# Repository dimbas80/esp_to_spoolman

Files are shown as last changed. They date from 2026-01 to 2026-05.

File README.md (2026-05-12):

# ESP_TO_SPOOLMAN
Данный проект реализует считывание NFC меток типа NTAG2xx установленных на катушках с филаментом, и установку активной катушки в сервис [Spoolman]([https://github.com/ManuelW77/Filaman](https://github.com/Donkie/Spoolman#integration-status))  через Moonraker. Spoolman должен быть установлен и настроен в вашей сети и принтере.
## Используемые компоненты
1. Контроллер ESP32-C3 super mini
2. Считыватель NFC меток RFID-RC522
3. Светодиод WS2812B
4. Кнопка
5. Метки NTAG215, NTAG216
   
Проект выполнен для ESP32-C3 но можно установить на другой тип ESP32  с заменой пинов на соотвествующие.
Имеется web-интерфейс для настройки wifi и адресов серверов Spoolman и Moonraker. Так же там отображается состояние доступности серверов, считывателя и данные полученные с метки.

## Запись меток
Запись меток осуществляется с помощью проекта [FilaMan](https://github.com/ManuelW77/Filaman)
Метки можно применять такие NTAG215 
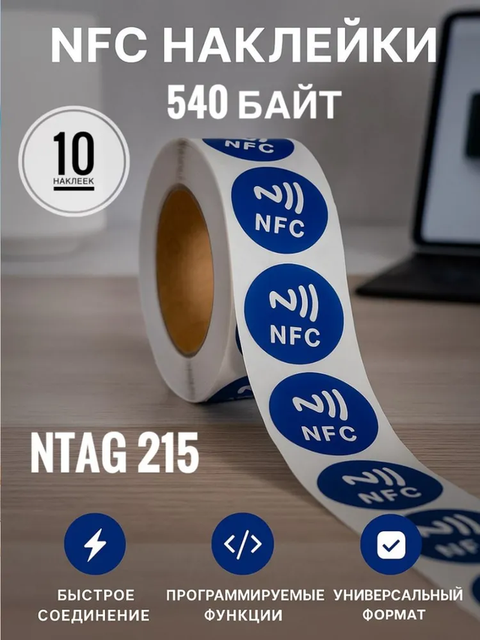
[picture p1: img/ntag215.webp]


## СХЕМА
Схема подключения модуля и ESP32

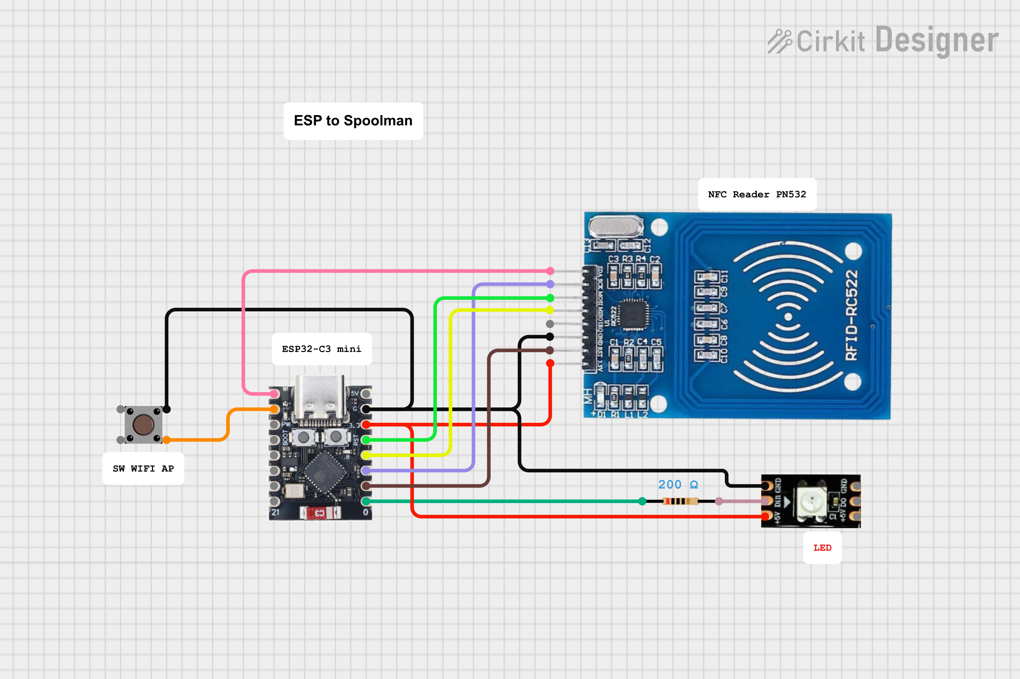
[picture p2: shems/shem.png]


## Pinout ESP32-C3 super mini
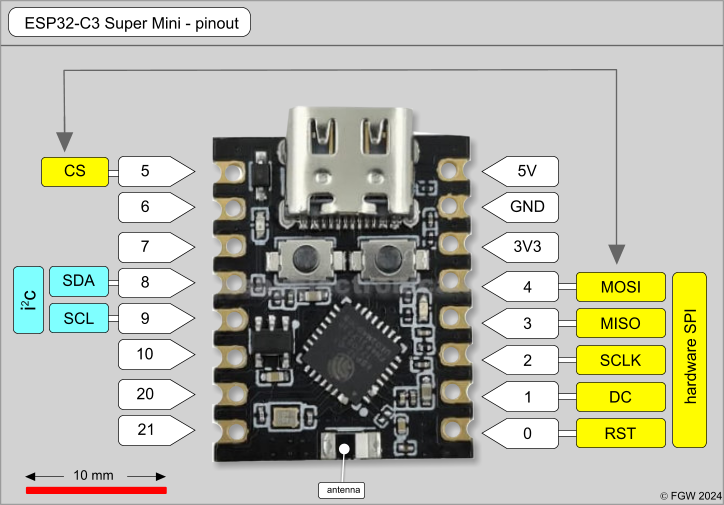
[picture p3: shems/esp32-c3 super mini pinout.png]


## Работа устройства
При включении ESP создает точку доступа с именем "ESP to Spoolman" и будет мигать синий светодиод к которой необходимо подключиться и перейти по IP 192.168.4.1. В  настройках необходимо ввести данные свой wifi сети, IP адрес сервера Spoolman, и IP адрес сервера Moonraker (ваш принтер с Klipper). И нажать кнопку "Save&Restart". После переподключения должны гореть зеленые светодиоды о доступности серверов и считывателя NFC. При необходимости нажать кнопку "Проверка статуса серверов". Светодиод на устройстве должен гороть зеленым. При поднисении метки к считывателю и успешном считывании метки светодиод мигнет желтым и установиться текущая катушка в web-интерфейсе вашего принтера. В случае ошибки чтения метки светодиод мигнет красным. Если красный горит постоянно значить потеряна связь с сервером или сетью. Подробный вывод ошибок и текущего состояния можно увидеть в логе в web-интерфейсе.

При включении переключателя "Устанавливать в MMU" будет также отправляться на принтер команда MMU_GATE_MAP NEXT_SPOOLID="spool_id". При этом если вы за время указанное в настройках вашего Happy Hare вставите в затвор пруток, то он установиться к карту затворов. Интеграция Happy Hare и Spoolman должна быть включена

## Вид web-интерфейса устройства
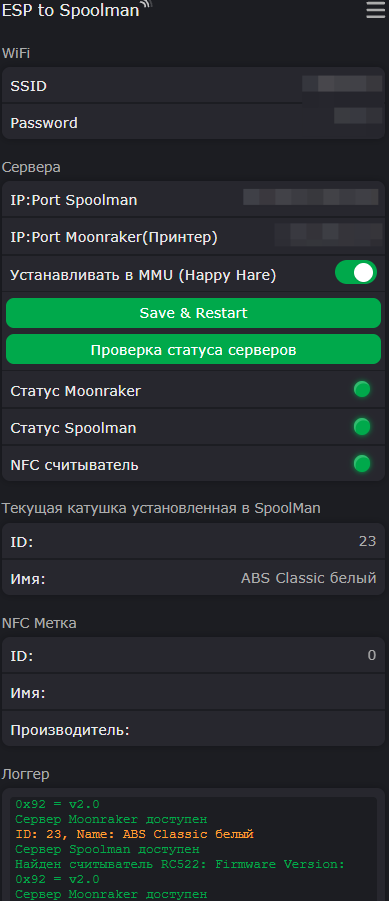
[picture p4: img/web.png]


## Вид web-интерфейса принтера с установленной катушкой
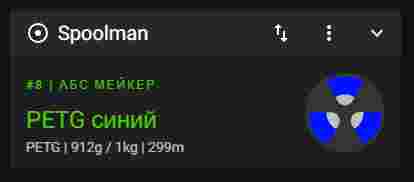
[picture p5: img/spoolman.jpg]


## Общий вид устройства
Файлы для печати доступны в папке cad

Общий вид устройства в корпусе 

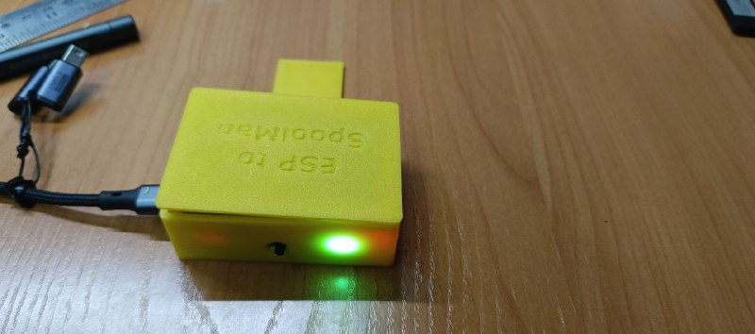
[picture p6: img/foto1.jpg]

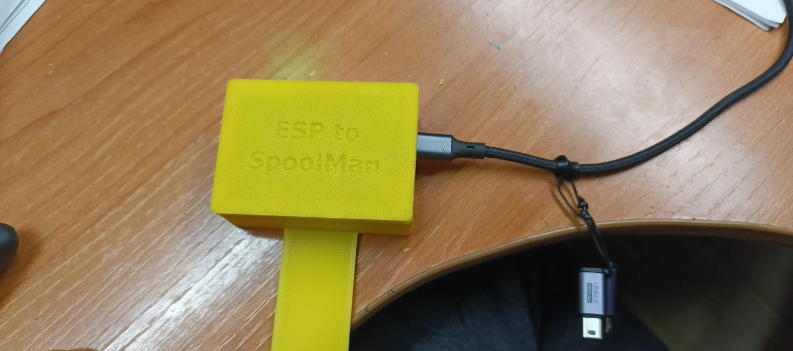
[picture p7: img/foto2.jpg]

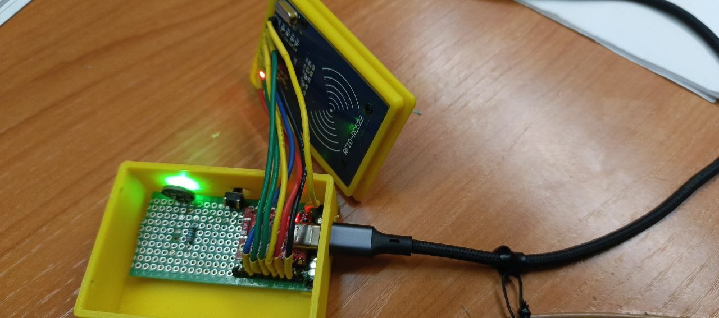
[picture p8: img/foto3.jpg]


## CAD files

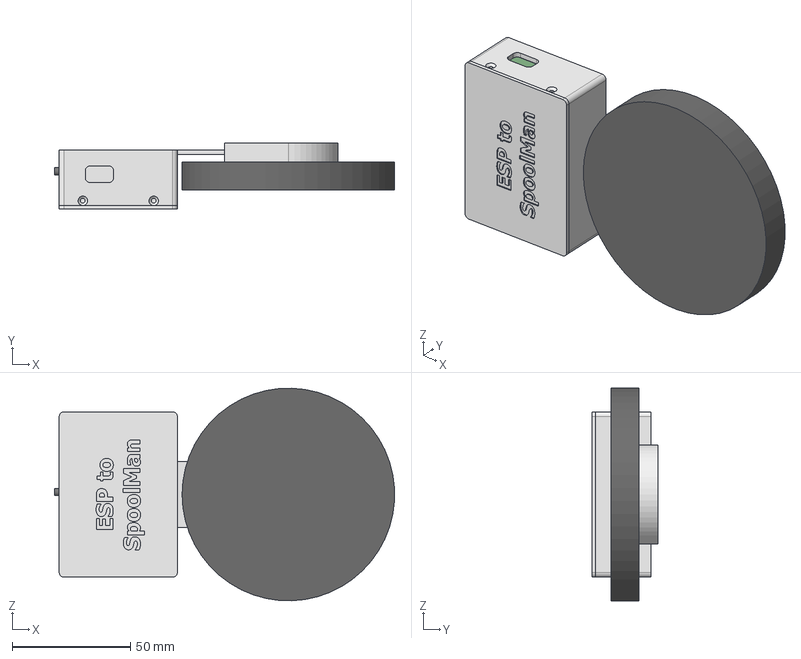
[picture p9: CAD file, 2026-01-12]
cad/ESP_to_Spoolman.stp
143.9 x 28.0 x 90.0 mm
Основа
RC522
Держатель катушки
КорпусNFC
Макетная плата 30х70
ESP32-C3_super_mini_scaled
Кнопка 6х6 на плату v2
Крышка

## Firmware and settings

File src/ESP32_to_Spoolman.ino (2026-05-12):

/*
Установка по NFC метке катушки в очередь печати Spoolman, Moonraker
автор: Dimbas80
*/
#define VER "1.0"
////////////////////////
//Библиотеки
///////////////////////

//ПИНЫ
#define SW_WIFI 6  //Пин Кнопки перевода в режим АР при загрузке

#include <WiFi.h>
#include <HTTPClient.h>
#include <StringUtils.h>
#include <Arduino.h>
#include <ArduinoJson.h>

//Светодиод WS2812
#include <FastLED.h>
#define NUMLEDS 1
#define PIN_DATA 0
#define BRIGHTNESS 100
#define LED_TYPE WS2812B
#define COLOR_ORDER GRB
#define RED 0
#define BLUE 150
#define GREEN 100
#define YELLOW 30
#define LIME 60

CRGB leds[NUMLEDS];

//============= NFC MFRC522 ===============
#include <MFRC522v2.h>
#include <MFRC522DriverSPI.h>
#include <MFRC522DriverPinSimple.h>
#include <MFRC522Debug.h>
#define RST_PIN 1  // Configurable, see typical pin layout above
#define SS_PIN 5   // Configurable, see typical pin layout above

MFRC522DriverPinSimple ss_pin(SS_PIN);  // Create pin driver. See typical pin layout above.
MFRC522DriverSPI driver{ ss_pin };      // Create SPI driver.
MFRC522 mfrc522{ driver };              // Create MFRC522 instance.

//=================== DB ==================
#include <GyverDBFile.h>
#include <LittleFS.h>
GyverDBFile db(&LittleFS, "/data.db");

#include <SettingsGyver.h>
SettingsGyver sett("ESP to Spoolman", &db);

sets::Logger logger(2000);  // размер буфера

WiFiServer server(80);

//имена ячеек базы данных
DB_KEYS(
  web,
  wifi_ssid,
  wifi_pass,
  serverSpoolman,
  serverMoonraker,
  apply1,
  apply2,
  led_sp,
  led_mn,
  led_nfc,
  sw_mmu,
  id,
  filament,
  nfc_id,
  nfc_name,
  nfc_brand,
  nfc_color,
  nfc_par);

//Переменные
bool LED_SP = false;        // WEB светодиод доступности спулман
bool LED_MN = false;        // WEB светодиод доступности Moonraker
bool LED_NFC = false;       // WEB светодиод доступности NFC считывателя
int curentID;               // ID текущей катушки
const char* filament_name;  // Имя филамента
bool wifiSettingMode = 0;   //Перемнная режима WIFI. 0 - SSID, 1 - AP
bool fl_status = false;     //флаг статуса
bool fl_led = false;        //флаг led
bool mmu = false;           //включение отправки данныех в MMU


//===========Таймеры=====================
#include <TimerMs.h>
TimerMs T_LED_WIFI(500, 1, 0);   //Периодичность мигания светодиода WIFI
TimerMs ResetLED(1000, 1, 0);    //Таймер сброса светодиода
TimerMs RebootNFC(60000, 1, 0);  //Таймер сброса NFC против зависания

//Интерфейс настроек
void build(sets::Builder& b) {
  {
    sets::Group g(b, "WiFi");
    b.Input(web::wifi_ssid, "SSID");
    b.Pass(web::wifi_pass, "Password");
  }
  {
    sets::Group g(b, "Сервера");
    if (b.Input(web::serverSpoolman, "IP:Port Spoolman")) {
      logger.println("Set IP:Port Spoolman:" + String(db[web::serverSpoolman]));
      db.update();
      //statusServer();
      //curent_filament_name(curentID);
    }
    if (b.Input(web::serverMoonraker, "IP:Port Moonraker(Принтер)")) {
      logger.println("Set IP:Port Moonraker(Принтер):" + String(db[web::serverMoonraker]));
      db.update();
      //statusServer();
    }
    //Переключатель MMU
    if (b.Switch(web::sw_mmu, "Устанавливать в MMU (Happy Hare)", &mmu)) {
      // Если по клику на переключатель мы хотим сохранить значение сразу:
      db[web::sw_mmu] = mmu;  // Синхронизируем значение с базой данных
      db.update();            // Записываем в ПЗУ
    }

    if (b.Button(web::apply1, "Save & Restart")) {
      db.update();  // сохраняем БД не дожидаясь таймаута
      ESP.restart();
    }
    if (b.Button(web::apply2, "Проверка статуса серверов")) {
      fl_status = true;
    }
    b.LED(web::led_mn, "Статус Moonraker", LED_MN, sets::Colors::Yellow, sets::Colors::Green);
    b.LED(web::led_sp, "Статус Spoolman", LED_SP, sets::Colors::Yellow, sets::Colors::Green);
    b.LED(web::led_nfc, "NFC считыватель", LED_NFC, sets::Colors::Yellow, sets::Colors::Green);
  }
  {
    sets::Group g(b, "Текущая катушка установленная в SpoolMan");
    b.Label(web::id, "ID:");
    b.Label(web::filament, "Имя:");
  }
  {
    sets::Group g(b, "NFC Метка");
    b.Label(web::nfc_id, "ID:");
    b.Label(web::nfc_name, "Имя:");
    b.Label(web::nfc_brand, "Производитель:");
    //b.Label(web::nfc_color, "Цвет:");
  }

  {
    sets::Group g(b, "Логгер");
    b.Log(H(log), logger);
  }
}


void update(sets::Updater& upd) {
  // отправить лог
  upd.update(H(log), logger);
}


/*==================================
            S E T U P 
====================================
*/
void setup() {
  Serial.begin(115200);
  T_LED_WIFI.setPeriodMode();
  RebootNFC.setPeriodMode();
  ResetLED.setPeriodMode();

  //============Светодиод=============
  FastLED.addLeds<LED_TYPE, PIN_DATA, COLOR_ORDER>(leds, NUMLEDS);
  FastLED.setBrightness(BRIGHTNESS);
  FastLED.clear();
  FastLED.show();

  //============= WIFI ===============

  WiFi.mode(WIFI_AP_STA);

  //============= Web интерфейс ===============

  sett.begin();
  sett.onBuild(build);
  sett.onUpdate(update);
  sett.config.updateTout = 1000;
  sett.setVersion(VER);


  //Инициализация базы данных настроек
  LittleFS.begin(true);
  db.begin();
  db.init(web::wifi_ssid, "");
  db.init(web::wifi_pass, "");
  db.init(web::serverMoonraker, "");
  db.init(web::serverSpoolman, "");
  db.init(web::nfc_id, 0);
  db.init(web::nfc_name, "");
  db.init(web::nfc_brand, "");
  db.init(web::nfc_color, "");
  db.init(web::id, 0);
  db.init(web::filament, "");
  mmu = db[web::sw_mmu]; 
  db[web::nfc_id] = 0;
  db[web::nfc_name] = "";
  db[web::nfc_brand] = "";
  db[web::nfc_color] = "";
  db[web::id] = 0;
  db[web::filament] = "";

  //Входы выходы
  pinMode(SW_WIFI, INPUT_PULLUP);  //Кнопка сброса WIFI


  //============ WIFI AP ========
  //Включаем точку доступа при нажатой кнопке или если не задан логин
  if (digitalRead(SW_WIFI) == 0 or !db[web::wifi_ssid].length()) {
    wifiSettingMode = 1;
    // ======= AP =======
    WiFi.softAP("AP ESP_to_Spoolman");
    Serial.print("AP IP: ");
    Serial.println(WiFi.softAPIP());
  }


  // ======= STA =======
  // если логин задан - подключаемся
  if (digitalRead(SW_WIFI) == 1 and db[web::wifi_ssid].length()) {
    wifiSettingMode = 0;
    WiFi.begin(db[web::wifi_ssid], db[web::wifi_pass]);
    Serial.print("Connect STA");
    int tries = 20;
    while (WiFi.status() != WL_CONNECTED) {
      delay(500);
      Serial.print('.');
      if (!--tries) break;
    }
    Serial.println();
    Serial.print(F("IP: "));
    Serial.println(WiFi.localIP());
    server.begin();
    WiFi.softAPdisconnect(true);
  }

  if (WiFi.status() == WL_CONNECTED) {
    statusServer();
    curent_filament_name(curentID);
  }

  //============= инициализация считывателя RC522 ===============

  pinMode(RST_PIN, OUTPUT);
  digitalWrite(RST_PIN, HIGH);

  mfrc522.PCD_Init();                                      // Init MFRC522
  mfrc522.PCD_SetAntennaGain(0x07);                        // Установка усиления антенны
  mfrc522.PCD_AntennaOff();                                // Перезагружаем антенну
  mfrc522.PCD_AntennaOn();                                 // Включаем антенну
  MFRC522Debug::PCD_DumpVersionToSerial(mfrc522, Serial);  // Show details of PCD - MFRC522 Card Reader details.
  delay(100);

  if (mfrc522.PCD_PerformSelfTest()) {
    Serial.print("Найден считыватель RC522: ");
    MFRC522Debug::PCD_DumpVersionToSerial(mfrc522, Serial);  // Show version of PCD - MFRC522 Card Reader.
    logger.print("Найден считыватель RC522: ");
    MFRC522Debug::PCD_DumpVersionToSerial(mfrc522, logger);  // Show version of PCD - MFRC522 Card Reader.
    LED_NFC = true;
  } else {
    Serial.println("Не найден считыватель RC522");
    logger.println(sets::Logger::error() + "Не найден считыватель RC522");
    LED_NFC = false;
  }
}

/*=================================
         L O O P
===================================         
*/
void loop() {
  sett.tick();
  T_LED_WIFI.tick();
  ResetLED.tick();
  RebootNFC.tick();


  //Переодический ребут считывателя и проверка статуса серверов
  if (RebootNFC.ready()) {
    resetMFRC();
    statusServer();
    curent_filament_name(curentID);
  }

  //Переодический сброс флага светодиода
  if (ResetLED.ready()) {
    fl_led = false;
  }

  //Читаем метку
  if (mfrc522.PCD_PerformSelfTest()) {
    readNFC();
  }

  //Мигаем светодиодом в режиме АР
  if (wifiSettingMode == 1) {
    if (T_LED_WIFI.ready()) {
      leds[0].setHue(BLUE);
      FastLED.show();
    } else {
      FastLED.clear();
      FastLED.show();
    }
  }
  //При подключении WIFI и доступности серверов включаем светодиод
  if (fl_led == false and wifiSettingMode == 0) {
    if (wifiSettingMode == 0 and WiFi.status() == WL_CONNECTED) {
      leds[0].setHue(BLUE);
      FastLED.show();
      if (LED_MN == 1 and LED_SP == 1 and LED_NFC == true) {
        leds[0].setHue(GREEN);
        FastLED.show();
      }
    } else {
      leds[0].setHue(RED);
      FastLED.show();
    }
  }

  //Читаем Serial если "status", то выводим статус серверов и текующую установленную катушку, если число, то устанавливаем катушку с числом если найдена
  if (Serial.available()) {
    String i = Serial.readString();
    String status = F("status");
    if (i == status) {
      statusServer();
      curent_filament_name(curentID);
    } else {
      int setID = i.toInt();
      SetSpool(setID);
    }
  } else if (fl_status == true) {
    fl_status = false;
    statusServer();
    curent_filament_name(curentID);
  }
}


/*===============================
============ ФУНКЦИИ ============
=================================
*/
//Светодиод WS2812
void set_led_color(int color) {
  leds[0].setHue(color);
  FastLED.show();
  fl_led = true;
}

// Ошибка ответа сервера
void errorServer(String error) {
  Serial.println("Ошибка ответа сервера: " + String(error));
  logger.println(sets::Logger::error() + "Ошибка ответа сервера: " + String(error));
  set_led_color(RED);
  return;
}

//Сброс считываетля
void resetMFRC() {
  digitalWrite(RST_PIN, LOW);        // Сбрасываем модуль
  delayMicroseconds(100);            // Ждем
  digitalWrite(RST_PIN, HIGH);       // Отпускаем сброс
  mfrc522.PCD_Init();                // Инициализируем заного
  mfrc522.PCD_SetAntennaGain(0x07);  // Установка усиления антенны
  mfrc522.PCD_AntennaOff();          // Перезагружаем антенну
  mfrc522.PCD_AntennaOn();           // Включаем антенну
  Serial.println(F("Reboot RC522"));
  MFRC522Debug::PCD_DumpVersionToSerial(mfrc522, Serial);
  if (mfrc522.PCD_PerformSelfTest()) {
    Serial.println("Найден считыватель RC522: ");
    MFRC522Debug::PCD_DumpVersionToSerial(mfrc522, Serial);  // Show version of PCD - MFRC522 Card Reader.
    logger.print("Найден считыватель RC522: ");
    MFRC522Debug::PCD_DumpVersionToSerial(mfrc522, logger);  // Show version of PCD - MFRC522 Card Reader.
    LED_NFC = true;
  } else {
    Serial.println("Не найден считыватель RC522");
    logger.println(sets::Logger::error() + "Не найден считыватель RC522");
    LED_NFC = false;
  }
}

//Статус сервера
void statusServer() {
  if (WiFi.status() == WL_CONNECTED) {
    HTTPClient http;
    String geturl = "http://" + String(db[web::serverMoonraker]) + "/server/spoolman/status";

    http.begin(geturl);

    http.setFollowRedirects(HTTPC_FORCE_FOLLOW_REDIRECTS);
    http.addHeader("Content-Type", "application/json");

    int httpResponseCode = http.GET();

    if (httpResponseCode > 0) {
      String response = http.getString();
      JsonDocument doc;
      DeserializationError error = deserializeJson(doc, response);
      http.end();
      //Проверка на ошибки ответа от сервера
      if (error) {
        String err = error.f_str();
        errorServer(err);
        http.end();
        LED_MN = false;
        return;
      }

      bool statusServer = doc["result"]["spoolman_connected"];
      curentID = doc["result"]["spool_id"];
      db[web::id] = curentID;

      if (statusServer) {
        Serial.println("Сервер Moonraker доступен");
        logger.println("Сервер Moonraker доступен");
        LED_MN = true;
        sett.reload();
      } else {
        Serial.println("Сервер Moonraker не доступен");
        logger.println(sets::Logger::error() + "Сервер Moonraker не доступен");
        LED_MN = false;
        sett.reload();
        return;
      }
    } else {
      errorServer(String(httpResponseCode));
      http.end();
      LED_MN = false;
      return;
    }
  }
}

// Запрос имени катушки
const char* curent_filament_name(int ID) {

  // Block until we are able to connect to the WiFi access point
  if (WiFi.status() == WL_CONNECTED) {
    HTTPClient http;
    String geturl = "http://" + String(db[web::serverSpoolman]) + "/api/v1/spool";

    http.begin(geturl);

    http.setFollowRedirects(HTTPC_FORCE_FOLLOW_REDIRECTS);
    http.addHeader("Content-Type", "application/json");

    int httpResponseCode = http.GET();
    if (httpResponseCode > 0) {
      String payload = http.getString();
      JsonDocument doc;

      DeserializationError error = deserializeJson(doc, payload);
      http.end();
      //Проверка на ошибки ответа от сервера
      if (error) {
        String err = error.f_str();
        errorServer(err);
        filament_name = "0";
        db[web::filament] = filament_name;
        http.end();
        Serial.println("Сервер Spoolman не доступен");
        logger.println(sets::Logger::error() + "Сервер Spoolman не доступен");
        LED_SP = false;
        sett.reload();
        return filament_name;
      }
      //Максимум 1000 катушек
      for (int i = 0; i < 1000; i++) {
        int root_id = doc[i]["id"];
        if (root_id == 0) {
          filament_name = "0";
          db[web::filament] = filament_name;
          break;
        }
        if (root_id == ID) {
          filament_name = doc[i]["filament"]["name"];
          db[web::filament] = filament_name;
          Serial.println("ID: " + String(root_id) + ", Name: " + String(filament_name));
          logger.println(sets::Logger::warn() + "ID: " + String(root_id) + ", Name: " + String(filament_name));
          break;
        }
      }
      Serial.println("Сервер Spoolman доступен");
      logger.println("Сервер Spoolman доступен");
      LED_SP = true;
      sett.reload();
      return filament_name;
    } else {
      errorServer(String(httpResponseCode));
      http.end();
      filament_name = "0";
      db[web::filament] = filament_name;
      Serial.println("Сервер Spoolman не доступен");
      logger.println(sets::Logger::error() + "Сервер Spoolman не доступен");
      LED_SP = false;
      sett.reload();
      return filament_name;
    }
  }
  sett.reload();
  return filament_name;
}

//Запрос ID существующих катушек у Spoolman
bool getIDSpool(int ID) {
  bool IDexists = false;
  // Block until we are able to connect to the WiFi access point
  if (WiFi.status() == WL_CONNECTED) {
    HTTPClient http;
    String geturl = "http://" + String(db[web::serverSpoolman]) + "/api/v1/spool";

    http.begin(geturl);

    http.setFollowRedirects(HTTPC_FORCE_FOLLOW_REDIRECTS);
    http.addHeader("Content-Type", "application/json");

    int httpResponseCode = http.GET();
    if (httpResponseCode > 0) {
      String payload = http.getString();
      JsonDocument doc;
      DeserializationError error = deserializeJson(doc, payload);
      http.end();
      //Проверка на ошибки ответа от сервера
      if (error) {
        String err = error.f_str();
        errorServer(err);
        http.end();
        return IDexists;
      }
      //Максимум 1000 катушек
      for (int i = 0; i < 1000; i++) {
        int root_id = doc[i]["id"];
        if (root_id == 0) break;
        if (root_id == ID) IDexists = true;
      }
    } else {
      errorServer(String(httpResponseCode));
      http.end();
      return IDexists;
    }
  }
  sett.reload();
  return IDexists;
}

//Задание катушки с ID
void SetSpool(int SetID) {
  // Block until we are able to connect to the WiFi access point
  if (WiFi.status() == WL_CONNECTED) {
    if (getIDSpool(SetID)) {
      HTTPClient http;
      String geturl = "http://" + String(db[web::serverMoonraker]) + "/server/spoolman/spool_id";

      http.begin(geturl);

      http.setFollowRedirects(HTTPC_FORCE_FOLLOW_REDIRECTS);
      http.addHeader("Content-Type", "application/json");

      //Формируем документ JSON для отправки на сервер
      JsonDocument doc_post;  //Create json document
      doc_post["spool_id"] = SetID;

      String requestBody_post;
      serializeJson(doc_post, requestBody_post);
      //Отправка
      int httpResponseCode = http.POST(requestBody_post);
      //Ответ от сервера об отправке
      if (httpResponseCode > 0) {
        String response = http.getString();
        JsonDocument doc;
        DeserializationError error = deserializeJson(doc, response);
        if (error) {
          String err = error.f_str();
          errorServer(err);
          http.end();
          return;
        }
        int root_id = doc["result"]["spool_id"];
        Serial.println("Установка катушки с  ID: " + String(root_id));
        logger.println("Установка катушки с  ID: " + String(root_id));
        http.end();
      } else {
        errorServer(String(httpResponseCode));
        http.end();
      }
      http.end();
      statusServer();
      if (curentID == SetID) {
        Serial.println("Катушка с ID:" + String(SetID) + " успешно установлена");
        logger.println("Катушка с ID:" + String(SetID) + " успешно установлена");
        curent_filament_name(curentID);
        set_led_color(LIME);  //Включаем светодиод
      } else {
        Serial.println("Ошибка установки катушки с ID: " + String(SetID));
        logger.println(sets::Logger::error() + "Ошибка установки катушки с ID: " + String(SetID));
        set_led_color(RED);  //Включаем светодиод
      }
      sett.reload();
    } else {
      Serial.println("Катушка c ID: " + String(SetID) + " не существует");
      logger.println(sets::Logger::error() + "Катушка c ID: " + String(SetID) + " не существует");
      return;
    }
  }
  return;
}

// Задание следующей катушки с ID в MMU Happy Hare
void mmu_next_spoolid(int SetID) {
  if (WiFi.status() == WL_CONNECTED) {
    if (getIDSpool(SetID)) {
      //WiFiClient client;
      HTTPClient http;

      // Формируем URL для API Moonraker
      String url = "http://" + String(db[web::serverMoonraker]) + "/printer/gcode/script";

      http.begin(url);
      http.addHeader("Content-Type", "application/json");

      // Формируем JSON с командой для Happy Hare
      // Команда: MMU_GATE_MAP GATE=x NEXT_SPOOLID=y
      String httpRequestData = "{\"script\":\"MMU_GATE_MAP NEXT_SPOOLID=" + String(SetID) + "\"}";

      int httpResponseCode = http.POST(httpRequestData);

      if (httpResponseCode > 0) {
        Serial.println("Установка катушки с ID в MMU: " + String(SetID));
        logger.println("Установка катушки с ID в MMU: " + String(SetID));
        set_led_color(LIME);  //Включаем светодиод
      } else {
        Serial.println("Ошибка установки катушки с ID в MMU: " + String(SetID));
        logger.println(sets::Logger::error() + "Ошибка установки катушки с ID в MMU: " + String(SetID));
        set_led_color(RED);  //Включаем светодиод
      }
      http.end();
    }
  }
}
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

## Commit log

2026-05-11 Add files via upload
    Добавлена поддержа MMU Happy Hare
2026-11-11 refactor: sketch subfolder src/esp32_spoolman (folder name must match .ino); add .gitignore
2026-11-11 build: firmware v1.2 binaries (esp32c3 no_ota cdc)
2026-11-11 feat(v1.3): ndef parser + uid-first read dispatch
    Полный UID (hex UPPERCASE, 4/7/10 байт) вместо uint32-хеша для HTTP; NDEF TLV-парсер
    (0x03 + len/len16, заголовок записи TNF/SR/IL, пропуск служебных TLV, чтение с стр.4 до
    исчерпания TLV-длины, лимит 888 байт); UID-first через POST /api/v1/tag/scan
    (matched_spool_id), fallback содержимого: openspool spool_id -> FilaMan sm_id; поля
    nfc_* заполняются из JSON; VER 1.3 + лог версии в setup().
2026-11-11 feat(v1.3): tag write flow with lock check, vendor augmentation and two-step relink
2026-11-11 docs: agent notes, glossary, openspool tag sample, tests placeholder
2026-11-11 feat(v1.3.1): menu-based ui with settings submenu and grouped spool select
    D18: build() root is the main page (availability LEDs + check button, installed spool,
    read tag with new UID field, logger); Tabs removed, two beginMenu/endMenu pages:
    «Записать метку» (former write tab, writeMode/activation lock kept) and «Настройки»
    (wifi + Spoolman/Moonraker + firmware version). Page state lives in activePage, so
    writeMode follows menu entry instead of a stored tab key.
    D19: spool Select is sorted by material and labelled «material · brand · color · ID»
    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
2026-11-11 fix(v1.3.2): nfc reselect after nak, color names, menu order, logger in write menu, group font patch
    D23 (главное): tagPageReadable() при отказе MIFARE_Read делает HALT -> WUPA -> SELECT
    (новая tagReselect()) и возвращает исходный статус. После NAK от пробы 226 на NTAG215
    чтения 130/40 больше не уходят в STATUS_TIMEOUT (226=0xFF, 130=0x00 -> чип опознан).
    Исход переселекции и её отказы идут в диагностику (поле «переселекция» в логе).
    D24: подпись опции Select — «ID 37 · бренд · имя цвета». Имя цв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
2026-11-11 feat(v1.3.3): card uids link, mmu gates, color swatch, led semantics, boot reason
2026-11-11 build: v1.3.3 binaries (card uids, gates, swatch, led, file log, confirm)
2026-11-12 fix(v1.3.4): wait timeout, touch dedupe, visible confirm buttons, db_keу ids
2026-11-12 build: v1.3.4 binaries (wait timeout, dedupe, confirm buttons, card_uids unlink)
2026-11-12 fix(ui): red confirm-write button on linked tag
2026-11-12 fix(card_uids): empty list serializes as "" — spoolman rejects empty extra value with 400
2026-11-12 build: release packaging — only versioned full+ota images in build/
2026-11-12 fix(v1.3.7): non-blocking USB CDC logging — setTxTimeoutMs(0), loop stall without terminal
    Without a terminal the host stops draining the CDC FIFO: the 256-byte HWCDC
    TX ring fills and every Serial.println blocked loop() up to ~2 s
    (tx_timeout_ms=100 x 20 retries). Tag reads stretched to 25-30 s and
    HTTP requests hit their timeouts (reported as connection loss).
    Zero TX timeout drops excess debug output instead of blocking;
    the file logger still captures everything.
2026-11-12 docs: README for v1.3.7 — openspool format, own tag write/erase, tag api, changelog v1.3..v1.3.7; drop FilaMan references
2026-11-12 docs: web UI section — screenshots and descriptions of main, write-tag and settings pages
2026-11-13 chore: move release binaries from git tree to GitHub Releases
    build/*.bin gitignored; binaries are attached to the v<VER> release tag.
    History keeps old blobs — rewrite not done (destructive, needs owner call).
2026-11-13 fix v1.3.9: P2 review fixes — poll period, HTTP status gating, dead code
    - server polling 500ms -> 3s (new T_SERVERS timer; ex-T_LED_WIFI renamed to
    T_LED_AP, it only blinks blue in AP mode); sett.reload() only on displayed
    value change instead of every tick
    - HTTP success = 200 only in statusServer/curent_filament_name: 404/500 used
    to light the green 'server available' LED; /api/v1/spool/0 no longer polled
    - ARDUINOJSON_USE_DOUBLE moved above includes (was consumed before defined)
    - dead WiFiServer server(80) removed (begin() with no reader; port clash)
2026-11-13 fix v1.3.10: P3 review fixes — UID dedup hash, non-blocking serial, real CI
    - UID dedup hash: FNV-1a over all bytes (shift kept only last 4 bytes of
    7/10-byte UIDs — two tags with matching tails deduped into one)
    - serial commands read line-by-line without blocking loop (readString()
    stalled up to 1s per command); 'status' and spool-ID commands unchanged
    - CI: real arduino-cli compile (was blank template) with pinned core esp32
    3.3.10 and library versions == local build; README gains 'Зависимости';
    gitignore 'workflows/' anchored to root — it swallowed .github/workflows
    - hygiene: or/and -> ||/&&; AGENTS.md notes internal-only paths
2026-11-13 ci: pin BSON@2.3.5 — dependency of Settings, latest 3.x breaks its API
2026-11-13 fix v1.3.11: reload gated on spool_id only — spoolman_connected flip left stale LED_MN
2026-11-13 fix v1.3.12: String(F()) constructed every loop pass — heap churn regression
    v1.3.10 moved String status = F("status") out of if(Serial.available()):
    malloc/free at loop rate fragments the heap, intermittent HTTP/JSON/read
    failures on device. Compare against literal, zero allocations.
2026-11-13 fix v1.3.13: RxGain restore 0x07 -> 0x40 — 48 dB receiver overload on this antenna
    Device diag after 1.3.11/12: valid ATQA/SAK + UID, but page reads fail with
    status 0x07 (CRC) / 0x03 (timeout) — marginal comms at 48 dB. v1.3.7 actually
    ran at 0x40 the whole time (gain set before self-test was wiped by it) and
    read these tags stably. Keep restore-after-every-self-test, pin proven value.
